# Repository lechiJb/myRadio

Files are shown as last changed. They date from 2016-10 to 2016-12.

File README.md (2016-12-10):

# myRadio – ESP8266 WLAN radio

This project is based at following templates from Espressif:

ESP8266_MP3_DECODER
https://github.com/espressif/ESP8266_MP3_DECODER.git

ESP8266_RTOS_SDK
https://github.com/espressif/ESP8266_RTOS_SDK.git

The project provides a WLAN radio, based on an ESP8266-chip.
Audio-playback is streamed by use of the I2S-interface and an external I2S-DAC-chip.
All settings (stream-URL, stream-Port, WLAN-settings) are adjustable by an integrated HTML-server.

In chapter/folder “Hardware” you can find information about used hardware for this project.

Inside the project there are also CAD-file for a housing (see chapter “CAD” below) 
and simulation-files for calculating crossover network-components (see chapter “Boxsim” below). 

##Hardware
As esp-board I used following NodeMCU-Board:
https://github.com/nodemcu/nodemcu-devkit-v1.0

It has a esp12e-board integrated, but this code runs on a esp12f-board as well (other boards will also run, 
but I only tested esp12e and esp12f-boards).
Some users tested a esp12-board without success!!!!
For MP3-decoding a chip called PCM5102 is used. There are many cheep breakout-boards available. 
To select a stream-channel, a potentiometer is used. I used a linear potentiometer but a standard one is also fine.
All other used components are optional and can be replaced or removed depending of your project!

Following there is a list of all used components:
	Controller:
- NodeMCU-board https://github.com/nodemcu/nodemcu-devkit-v1.0
- PCM5102 breakout-board http://www.ebay.com/itm/Assembled-Board-PCM5102-DAC-Decoder-I2S-Player-32bit-384K-Beyond-ES9023-PCM1794-/311402292006

All following components are optional. They are used in my radio, 
but if you like to implement this code into your system, you might need other / less components 

 Amplifier:
- DROK® TA2024B amplifier-board https://www.amazon.com/DROK-Computer-Amplifier-Electric-Capacity/dp/B00C03YYCK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

Stream-Change:
- Linear potentiometer 10K mono http://www.ebay.com/itm/ALPS-Schieberegler-RSA0N12-Schiebeweg-100mm-Potentiometer-Poti-Fader-/260967189845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

Power-supply:
- Salcar Power-Supply 12V 3A 36W https://www.amazon.de/gp/product/B00LFB4GC6/ref=oh_aui_detailpage_o03_s00?ie=UTF8&psc=1
- Mini DC-DC step down converter http://www.ebay.com/itm/10pcs-Mini-360-DC-DC-4-75V-23V-to-1V-17V-Buck-Converter-Step-Down-Power-supply-/272362239425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
- Slide-Switch 2-way (for disconnecting power-supply from NodeMCU in case of USB-connection) 
- Connector for power supply C6 inclusive power-switch http://www.conrad-electronic.co.uk/ce/en/product/718564/IEC-connector-C6-Plug-horizontal-mount-Total-number-of-pins-2-PE-25-A-Black-1-pcs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 

Bluetooth-connection:
- KRC-86B http://www.ebay.com/itm/KRC-86B-CSR8630-Bluetooth-4-0-Module-Stereo-Audio-Receiver-Amplifier-Board-ST-/172339536663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

Speaker
- Monacor SP40 https://www.monacor.com/de-de/monacorinternational/marken/monacor/beschallungstechnik/lautsprechertechnik/hi-fi-breitbandlautsprecher/sp-40/
- Dayton ND20FA
http://www.daytonaudio.com/index.php/nd20fa-6-3-4-neodymium-dome-tweeter.html

Crossover Network
- Mundorf air coil L100, 2,2 mH/0,83 Ohm
- Mundorf air coil  L71, 0,47 mH/0,57 Ohm
- Capacitor MKT 10,0 uF / 250Vdc
- Capacitor MKT 2,2 uF / 250Vdc
- Resistor MOX5 12 Ohm 2%
- Resistor MOX5 1,0 Ohm 2%

## Compile code
For a successful code-compiling following components are required:

Linux operation system (used for Project: Debian 9.0 Stretch, others should work as well).
Also a virtual-machine should be fine.

esp-open-sdk:
	https://github.com/pfalcon/esp-open-sdk.git

gtkterm (optional, is used for reviewing serial output for debugging):
	Run following code in a terminal-window:
		sudo apt-get install gtkterm 

1. Clone and compile esp-open-sdk like described in the repository.

2. Clone this repository to your local computer

3. Edit following file “<path_to_repository>/mp3/compile-script.sh” by using a standard-editor like gedit or notepad++. Following entries must be adjusted:

		#-----------General settings -------------------
		ESPTOOL_PATH=/home/christian/Dokumente/esp8266/esp-open-sdk/esptool/esptool.py
		CROSSCOMPILER_PATH=/home/christian/Dokumente/esp8266/esp-open-sdk/xtensa-lx106-elf/bin

		#-----------Project settings -------------------
		#Keep PORT empty, to not flash the chip
		PORT=/dev/ttyUSB0	

		SDK_PATH=/home/christian/Dokumente/esp8266/myRadio

		PROJECT_PATH=$SDK_PATH/mp3

		BIN_PATH=$SDK_PATH/bin

		BINARY_FILE_1=$BIN_PATH/eagle.flash.bin
		START_BYTE_1=0x00000

		BINARY_FILE_2=$BIN_PATH/eagle.irom0text.bin
		START_BYTE_2=0x20000

		UART_SPEED=115200
		START_UART_AFTERWARDS=1

	Description:

		 ESPTOOL_PATH 		Path to esptool.py-file (used for flashing program at esp-chip)

		 CROSSCOMPILER_PATH 	Path to cross-compiler (included in esp-open-sdk)

		 PORT 			Link to Serial-Port, which is used for flashing esp-chip		 

		 SDK_PATH 		Path to esp-open-sdk

		 START_UART_AFTERWARDS	Start gtkterm after successful code-compiling. If gtkterm is not available, set this parameter to 0

	All other values are project-related and should not be changed!

4. Connect esp-chip to computer
5. Start code-compiling and flashing by running scirpt “compile-script.sh” with root privilegs:
	sudo ./<path_to_repository>/mp3/compile-script.sh

##How to use
Adjust settings by using html-server:

	1. switch poti to total maximum value (end-position of poti)
	2. After some seconds the esp-chip opens a wlan-hot-spot with SSID "myRadio" and no password.
	3. Connect to this hotspot
	4. Open your browser (google-chrome and firefox tested) and go to webside "http://192.168.4.1"
		
		Following adjustments are possible:

		WLAN-SSID		SSID for your home-network
		WLAN-Password		Password to your home-network

		Channel-count		Number of stream-channels, which should be used+

		For each channel:
		Link to channel		Link to stream-channel (without "http://")
		Port to channel		Port to stream-channel (often port 80)

		Save to flash		Save all settings to flash of esp-chip

	5. To exit config-server-mode, select another channel by changing poti-position
	6. Reboot device by refreshing homepage in browser or by disconnecting and connecting power-supply again
	7. Ready!!

Selecting channel
	
	Just use poti to select different channels...

Volume control
	
	Volum has to be controlled by the amplifier, which is connected to PCM5102-device.

##CAD
I designed a housing for my radio by using a web-CAD-service called OnShape:

	Link to CAD-Software:	https://www.onshape.com/
	Link to project:	https://cad.onshape.com/documents/0631abc9282a401a9c4bd0fe/w/ab4baf43f92f08b8f3445f90/e/15931d366a16f0a984bb5bd2

In folder "CAD" you can find all CAD-files and Drawings, which I created for this project.
After building all parts by use of plywook, I used some fleece inside the speaker box to avoid oscilation of echo effects.

After assembling all parts together you will need an additional front-cover for the radio. 

##Boxsim
To get really good sound, I used two speakers in my project:
	
	- Monacor SP40 
	- Dayton ND20FA
 
I also used a crossover network to optimize sound-quality. 
For simulation of the frequency-response of both speaker, I used an application called "Boxsim":

	Link to homepage: http://www.boxsim.de/	
	Link to download: http://www.boxsim.de/download/Boxsim120en.zip

In folder called "Boxsim" you can find my Boxsim-project.
To get a perfect sound, the frequency-response should be as straight as possible. 
In my project there is still a peak avalable at 5000Hz.
The sound, which I get, sounds really great, but I can heard some small "scratches" if someone speaks.
I don't know the reason for it. Maybe the esp-output is not perfect, some materials starts to oscilate, 
or the frequency-response is not perfect.
But I am really happy with the sound, so I will not optimize it any more.

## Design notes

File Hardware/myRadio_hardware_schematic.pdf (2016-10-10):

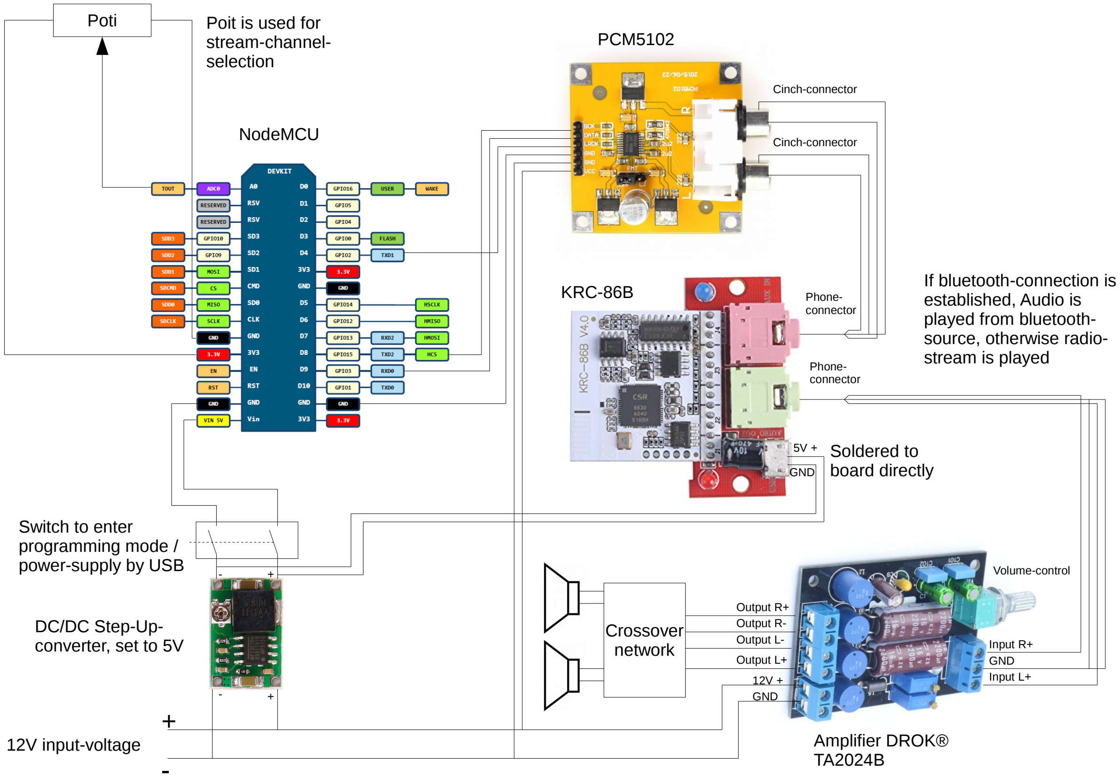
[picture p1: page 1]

Poti

NodeMCU

DC/DC Step-Upconverter, set to 5V

PCM5102

12V input-voltage

Switch to enter
programming mode /
power-supply by USB

+

Phoneconnector

Phoneconnector

Volume-control

Input R+

Input L+

GND

GND

12V +

5V +

GND

Cinch-connector

Cinch-connector

Soldered to
board directly

KRC-86B

+

+

Output R+

Output L+

Output L-

Output R- Crossover
network

Poit is used for
stream-channelselection

If bluetooth-connection is established, Audio is
played from bluetoothsource, otherwise radiostream is played

Amplifier DROK®
TA2024B

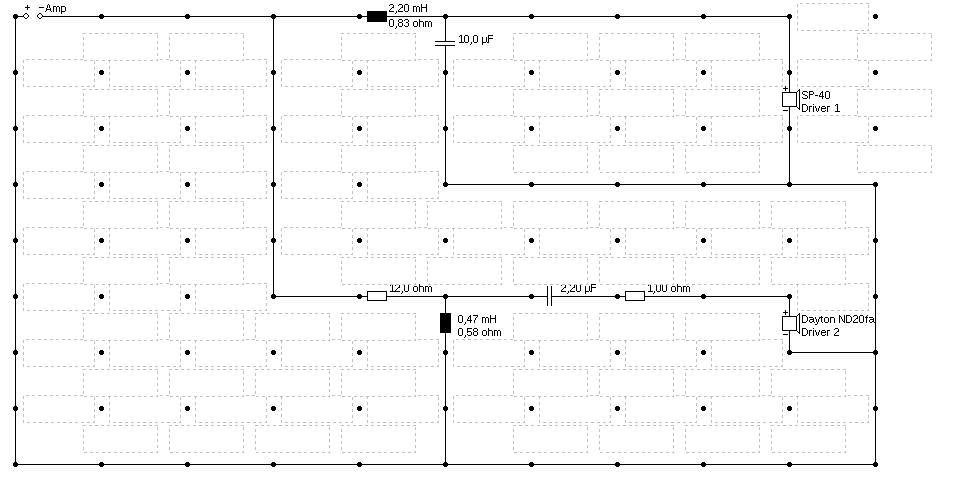
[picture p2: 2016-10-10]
Boxsim/Crossover_network.png

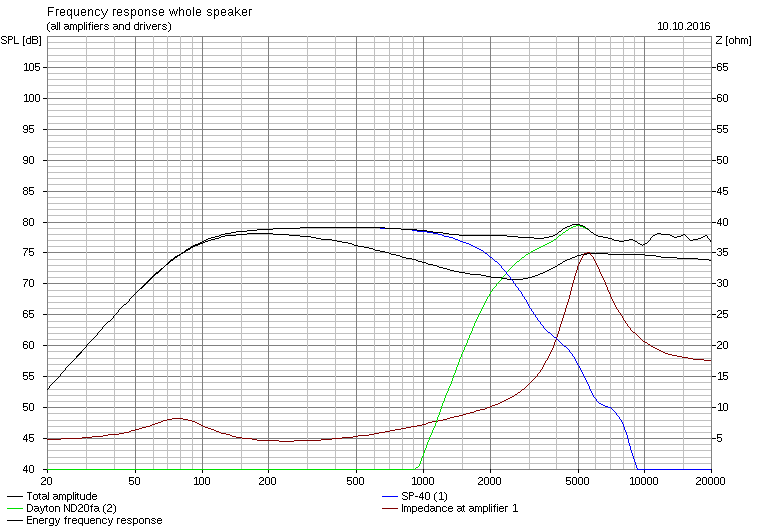
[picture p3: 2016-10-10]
Boxsim/Frequency_response.png

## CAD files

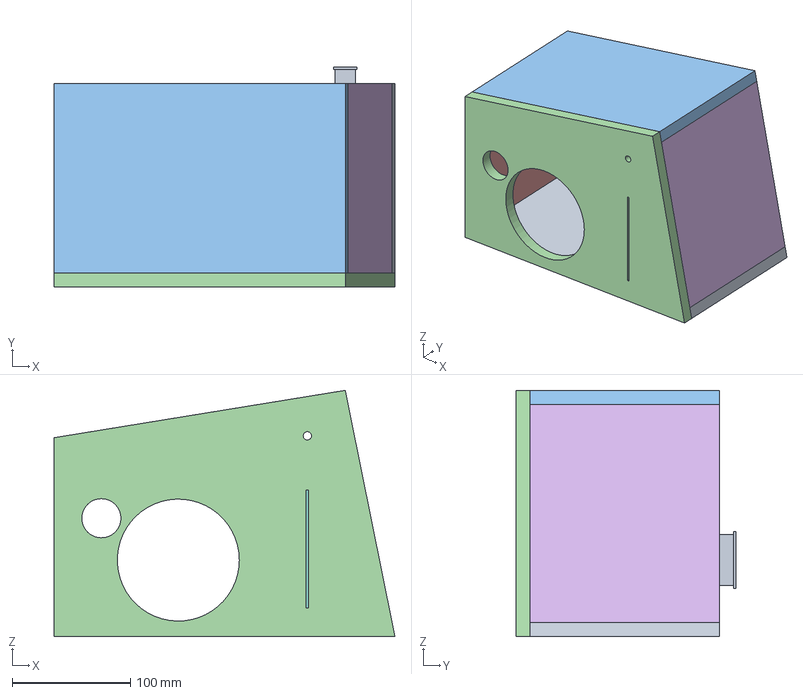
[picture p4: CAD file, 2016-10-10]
CAD/Assembly/Assembly 1.step
288.0 x 186.0 x 208.0 mm
Bodenplatte
Deckel1
Deckel2
Frontplatte
Abgrenzung
Seite_Links
Seite_Rechts
Netzteil

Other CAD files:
CAD/Drawings_DWG/myBox2 - Bodenplatte Drawing 1.dwg
CAD/Drawings_DWG/myBox2 - Abgrenzung Drawing 1.dwg
CAD/Drawings_DWG/myBox2 - Deckel2 Drawing 1.dwg
CAD/Drawings_DWG/myBox2 - Deckel1 Drawing 1.dwg
CAD/Drawings_DWG/myBox2 - Frontplatte Drawing 1.dwg
CAD/Drawings_DWG/myBox2 - Seite_Links Drawing 1.dwg
CAD/Drawings_DWG/myBox2 - RÃ¼ckplatte Drawing 1.dwg

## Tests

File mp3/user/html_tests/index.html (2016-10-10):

# myRadio - Settings

## Channel - count

How many radio-channels do you like to use?

## Channel - links

Link to channel 1:

Write data to flash

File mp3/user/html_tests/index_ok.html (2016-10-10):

# myRadio - Response

## Settings OK

Back to main-page

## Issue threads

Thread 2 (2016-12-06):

flash - Header-data does not match -1

Testi89, 2016-12-06:
When I flash the ESP with your code, I get the following error:

HW init. Wait for WIFI
mode : sta(a0:20:a6:0b:e7:05)
add if0
flash - Header-data does not match -1
flash - Err read header
init - Faild to read Flash
init - Write WLAN-Data
init - Write Channel-Data
channel - SetStream-Count, count=1
channel - StreamCount_old = 0
channel - SetStream-Host
channel - SetStream-Path, i=0, len=28
channel - SetStream-Port 0, port = 80
adc 223
adc - new stream = 0
START CLIENT MODE
scandone
wifi - SSID: Test_Pass
WIFI SSID Test_SSID set
WIFI Pass Test_Pass set
scandone
no Test_SSID found, reconnect after 1s
reconnect

Flashing was done to a new ESP12F with 32Mb flash, I also flashed esp_init_data_default.bin to 0x3fc000.

Maybe you can help? Thanks a lot!

lechiJb, 2016-12-10:
Hi!

after flashing you have to set the system to server-mode first.
You can do following steps:

1. Switch poti to maximum value ("adc 1024").
2. Board should boot in server mode ("START SERVER MODE")
3. You can search at a laptop or smartphone for a wlan hotspot called "myRadio" and connect to this hotspot.
4. Open a browser and go to homepage "http://192.168.1.4".
5. Setup your wlan-settings and channel-settings (press "OK" button after each setting to check, if entry is valid).
6. Press button "Write data to flash" to save all settings at flash of ESP.
7. now you can set the poti to a different value und no ESP should connect to your WLAN and to your defined stream-server after a reboot.

Greets,

Christian

Testi89, 2017-01-07:
Hello Christian,
now it is working, but I have a lot of drop-outs. ESP is connected 9 mbit/s.
Any ideas?
Thanks,
Pete

lechiJb, 2017-01-08:
did you changed something at following settings?

playerconfig.h
#define ADD_DEL_SAMPLES
#define ADD_DEL_BUFFPERSAMP (1000)
#define ADD_DEL_BUFFPERSAMP_NOSPIRAM (1500)

spiram_fifo.h
#define SPIRAMSIZE 1850

This lines have big influence to the audio-quality. If there are changes, audio-quality might be very low.
If you still have issues with audio-playback, you can try to install an external RAM-chip. Unfortunately I was not able to get an external RAM-chip working by use of the Node-MCU-board.

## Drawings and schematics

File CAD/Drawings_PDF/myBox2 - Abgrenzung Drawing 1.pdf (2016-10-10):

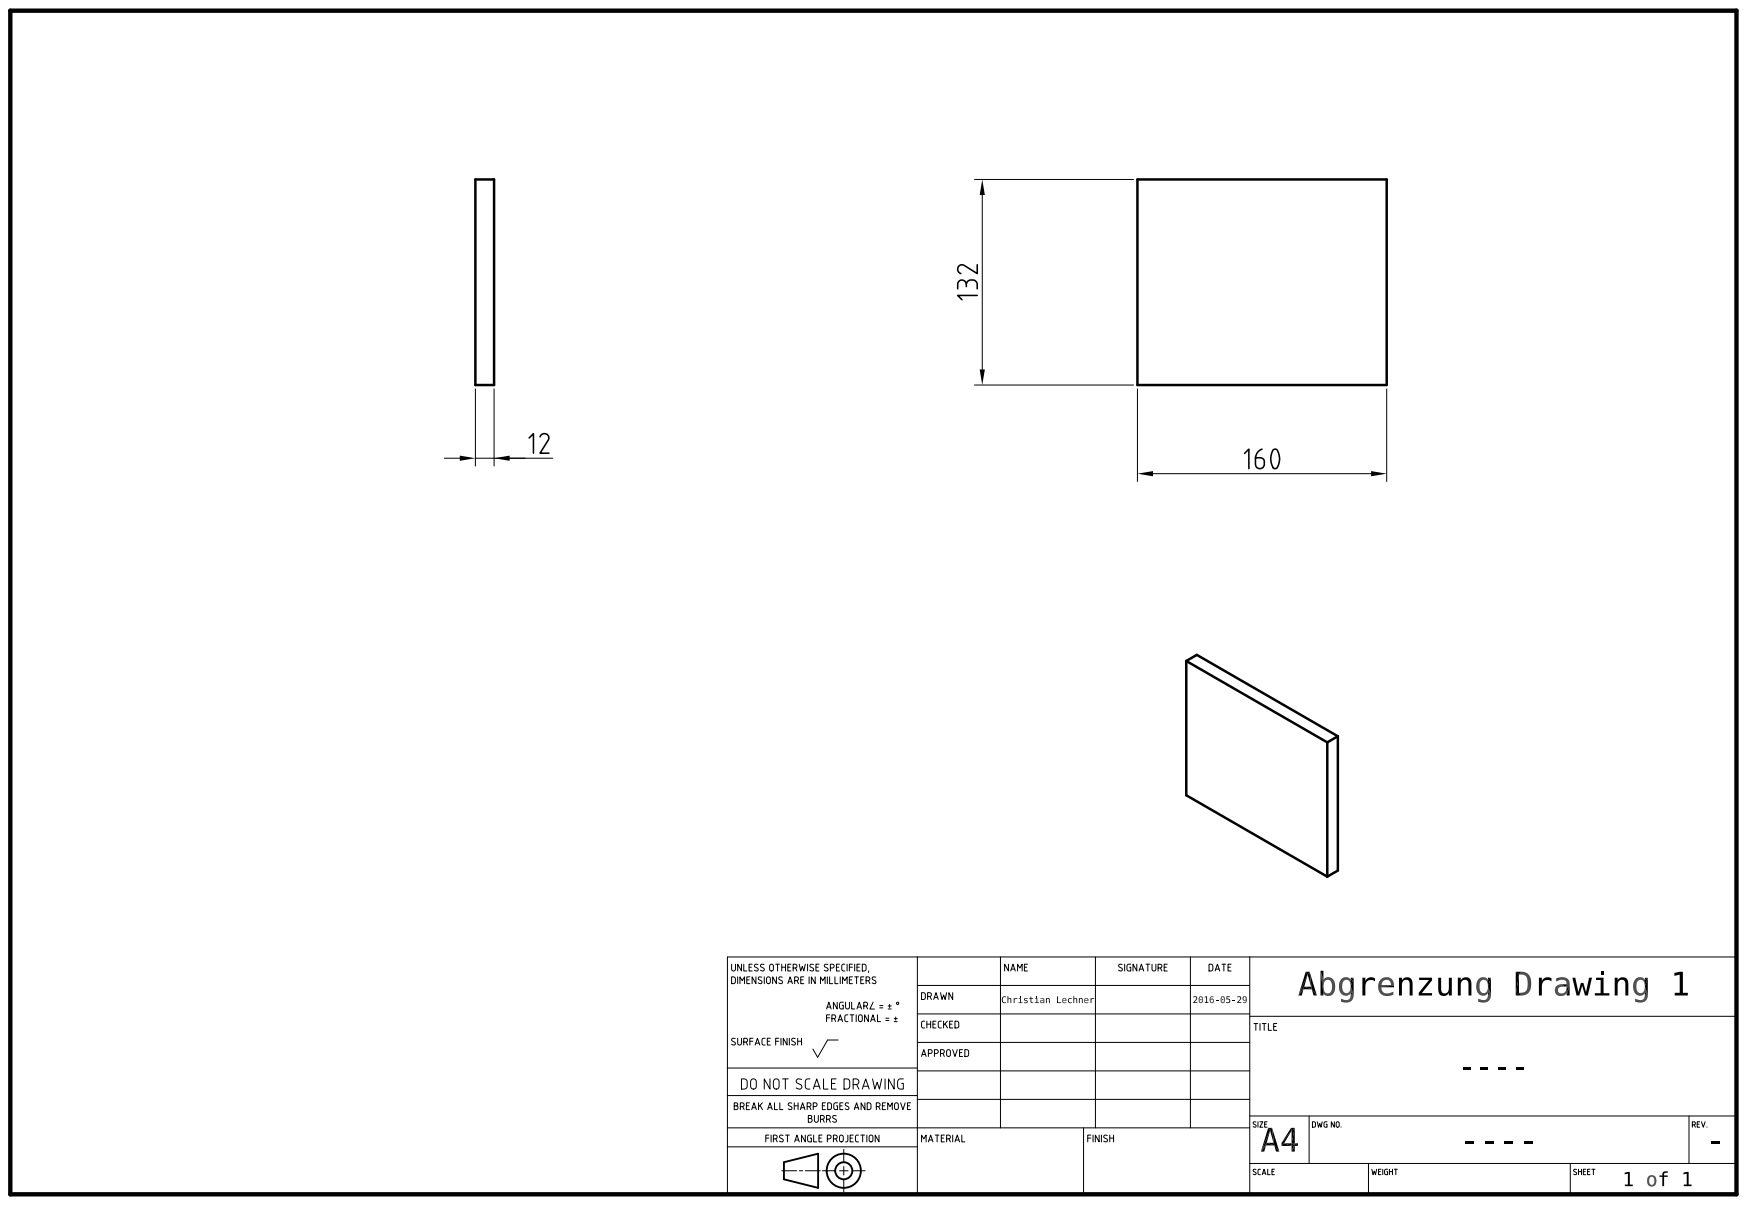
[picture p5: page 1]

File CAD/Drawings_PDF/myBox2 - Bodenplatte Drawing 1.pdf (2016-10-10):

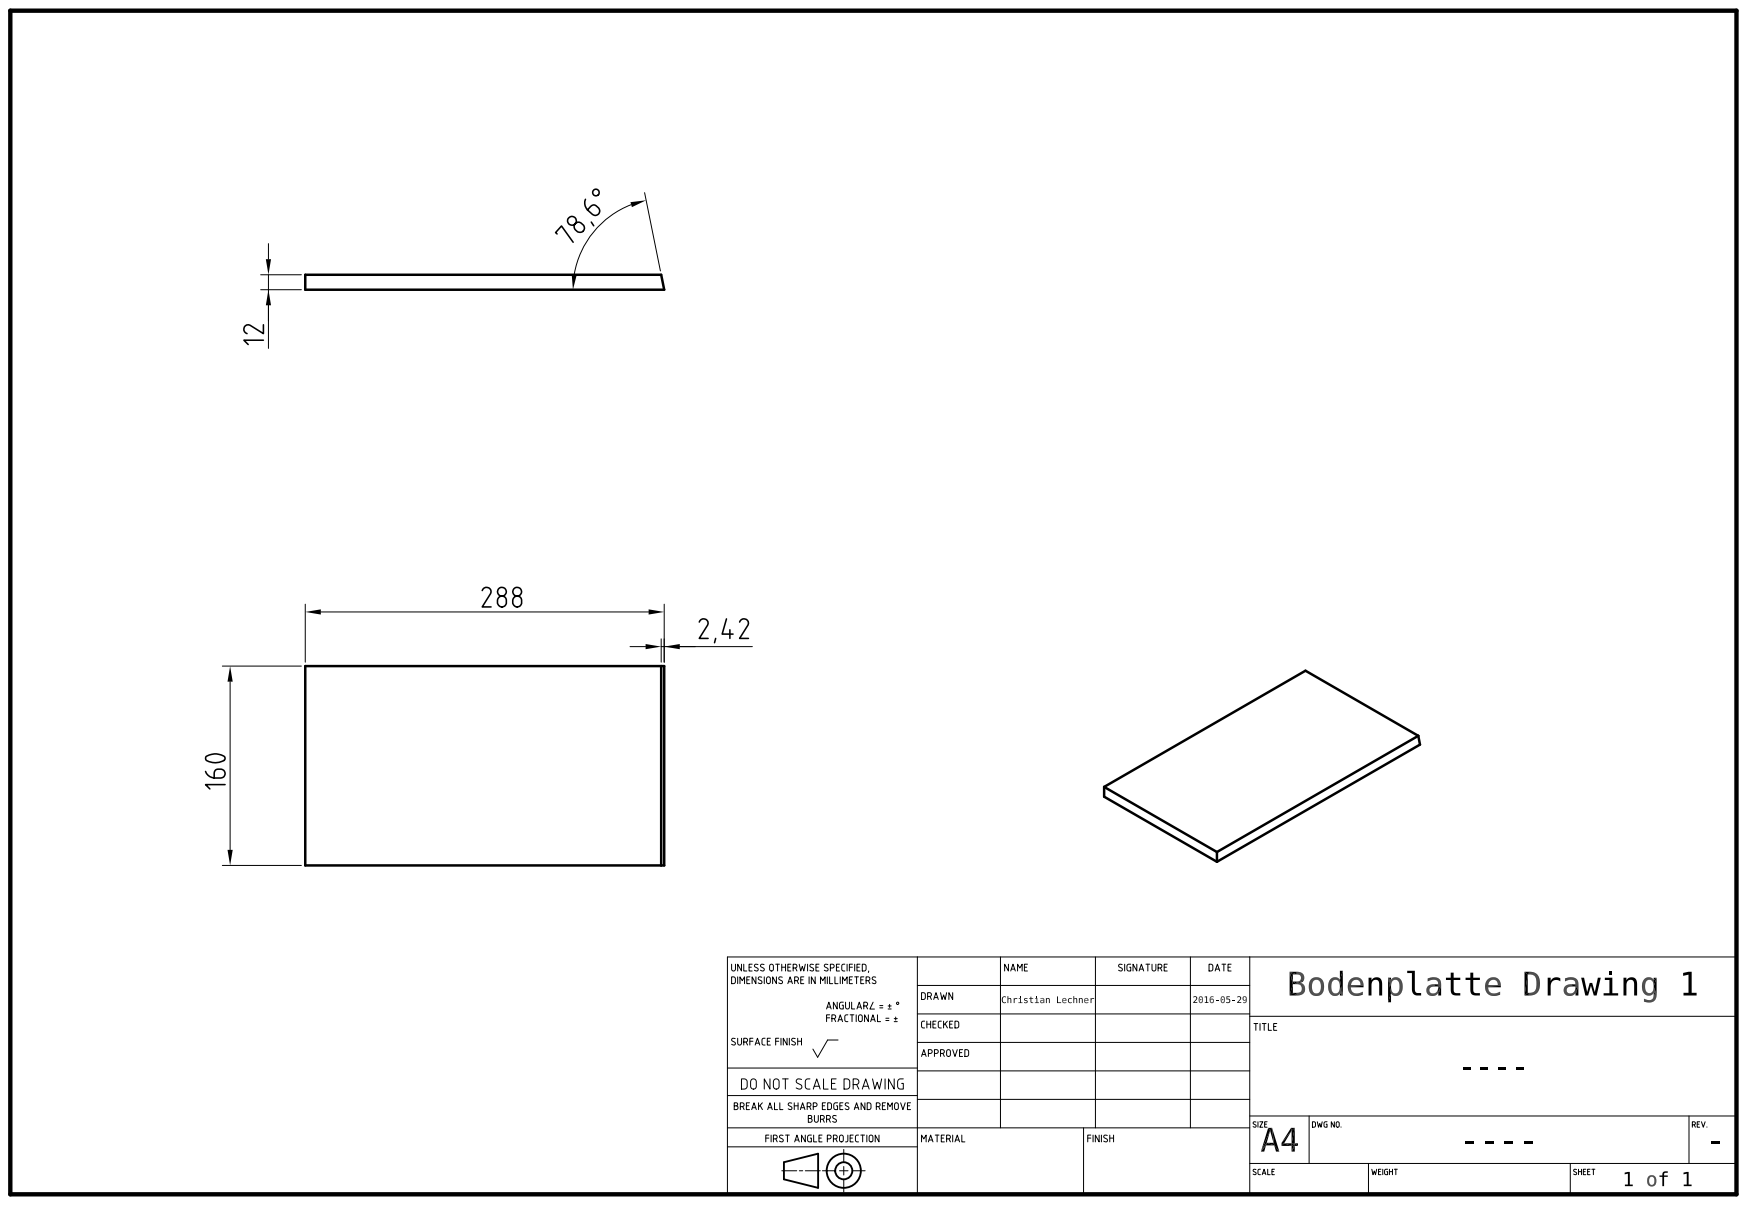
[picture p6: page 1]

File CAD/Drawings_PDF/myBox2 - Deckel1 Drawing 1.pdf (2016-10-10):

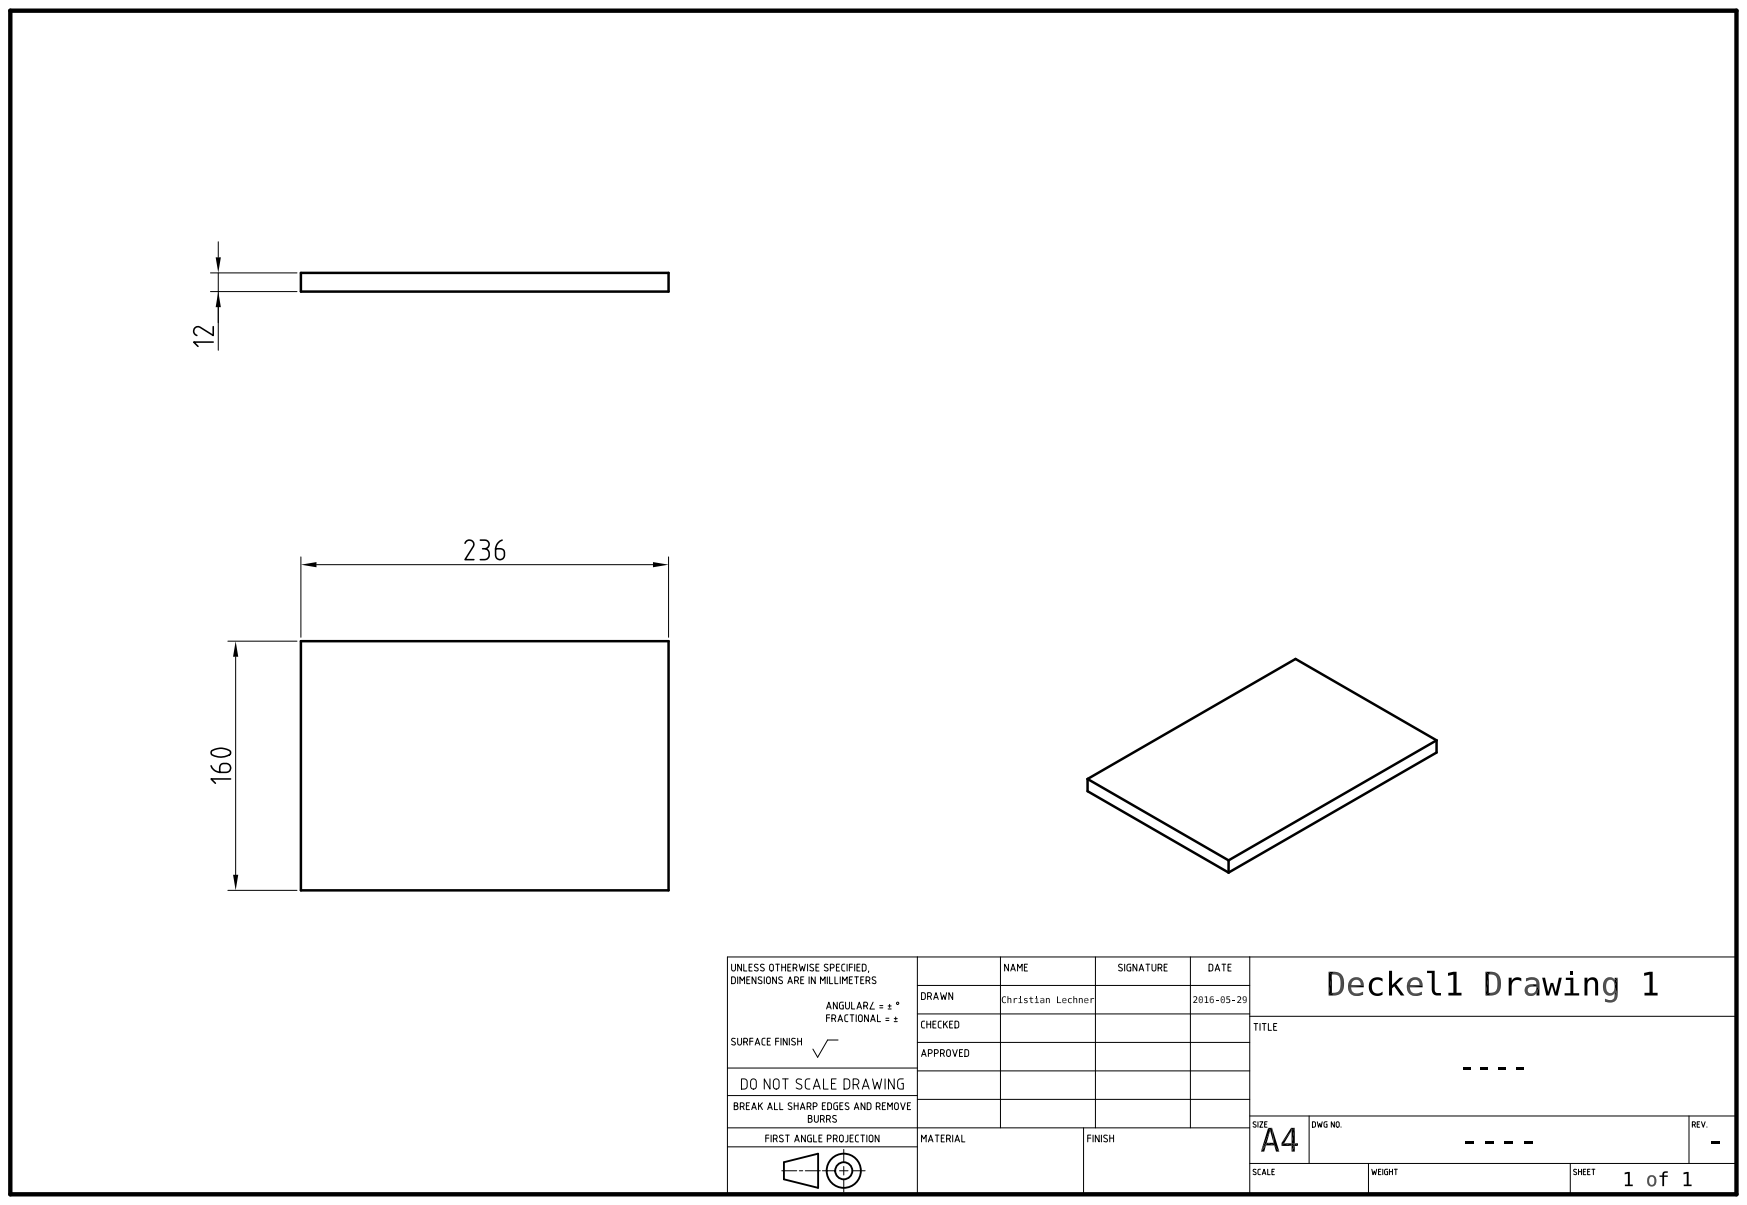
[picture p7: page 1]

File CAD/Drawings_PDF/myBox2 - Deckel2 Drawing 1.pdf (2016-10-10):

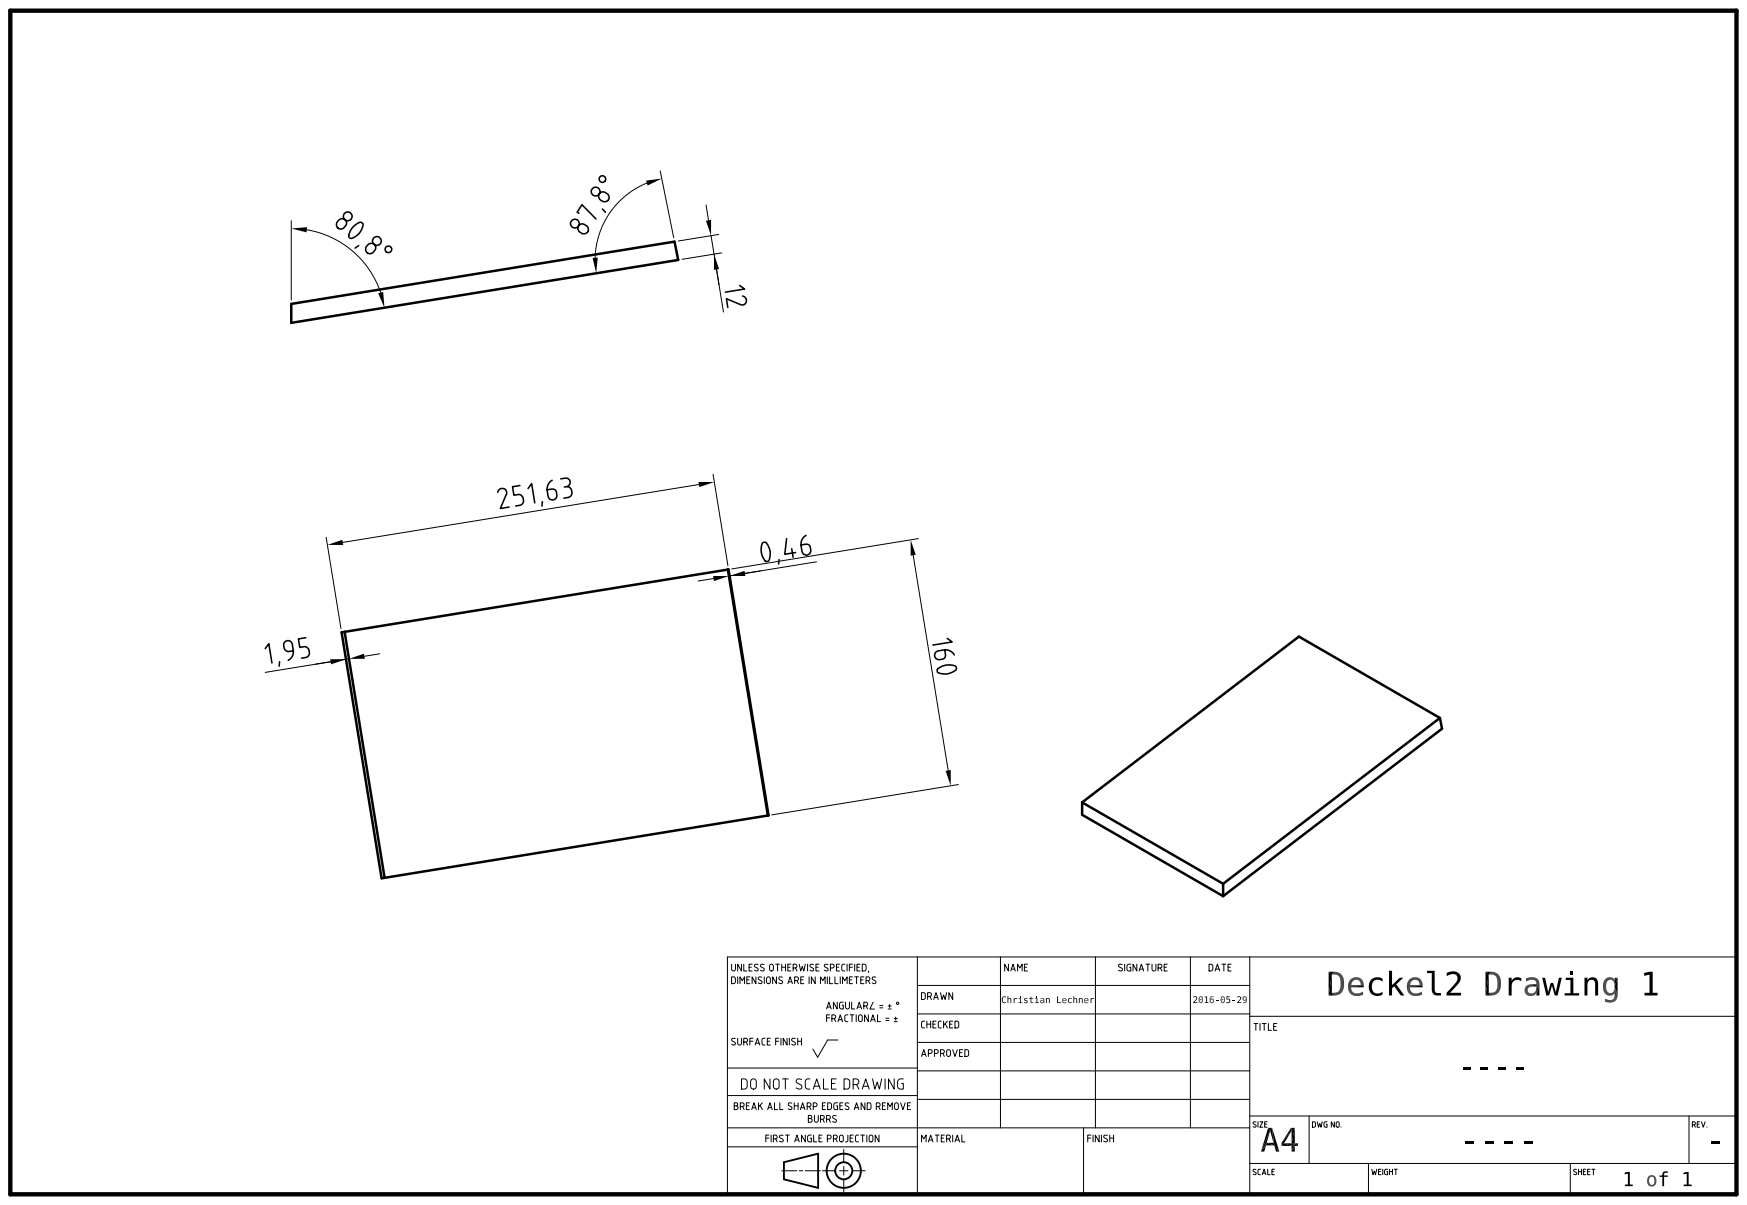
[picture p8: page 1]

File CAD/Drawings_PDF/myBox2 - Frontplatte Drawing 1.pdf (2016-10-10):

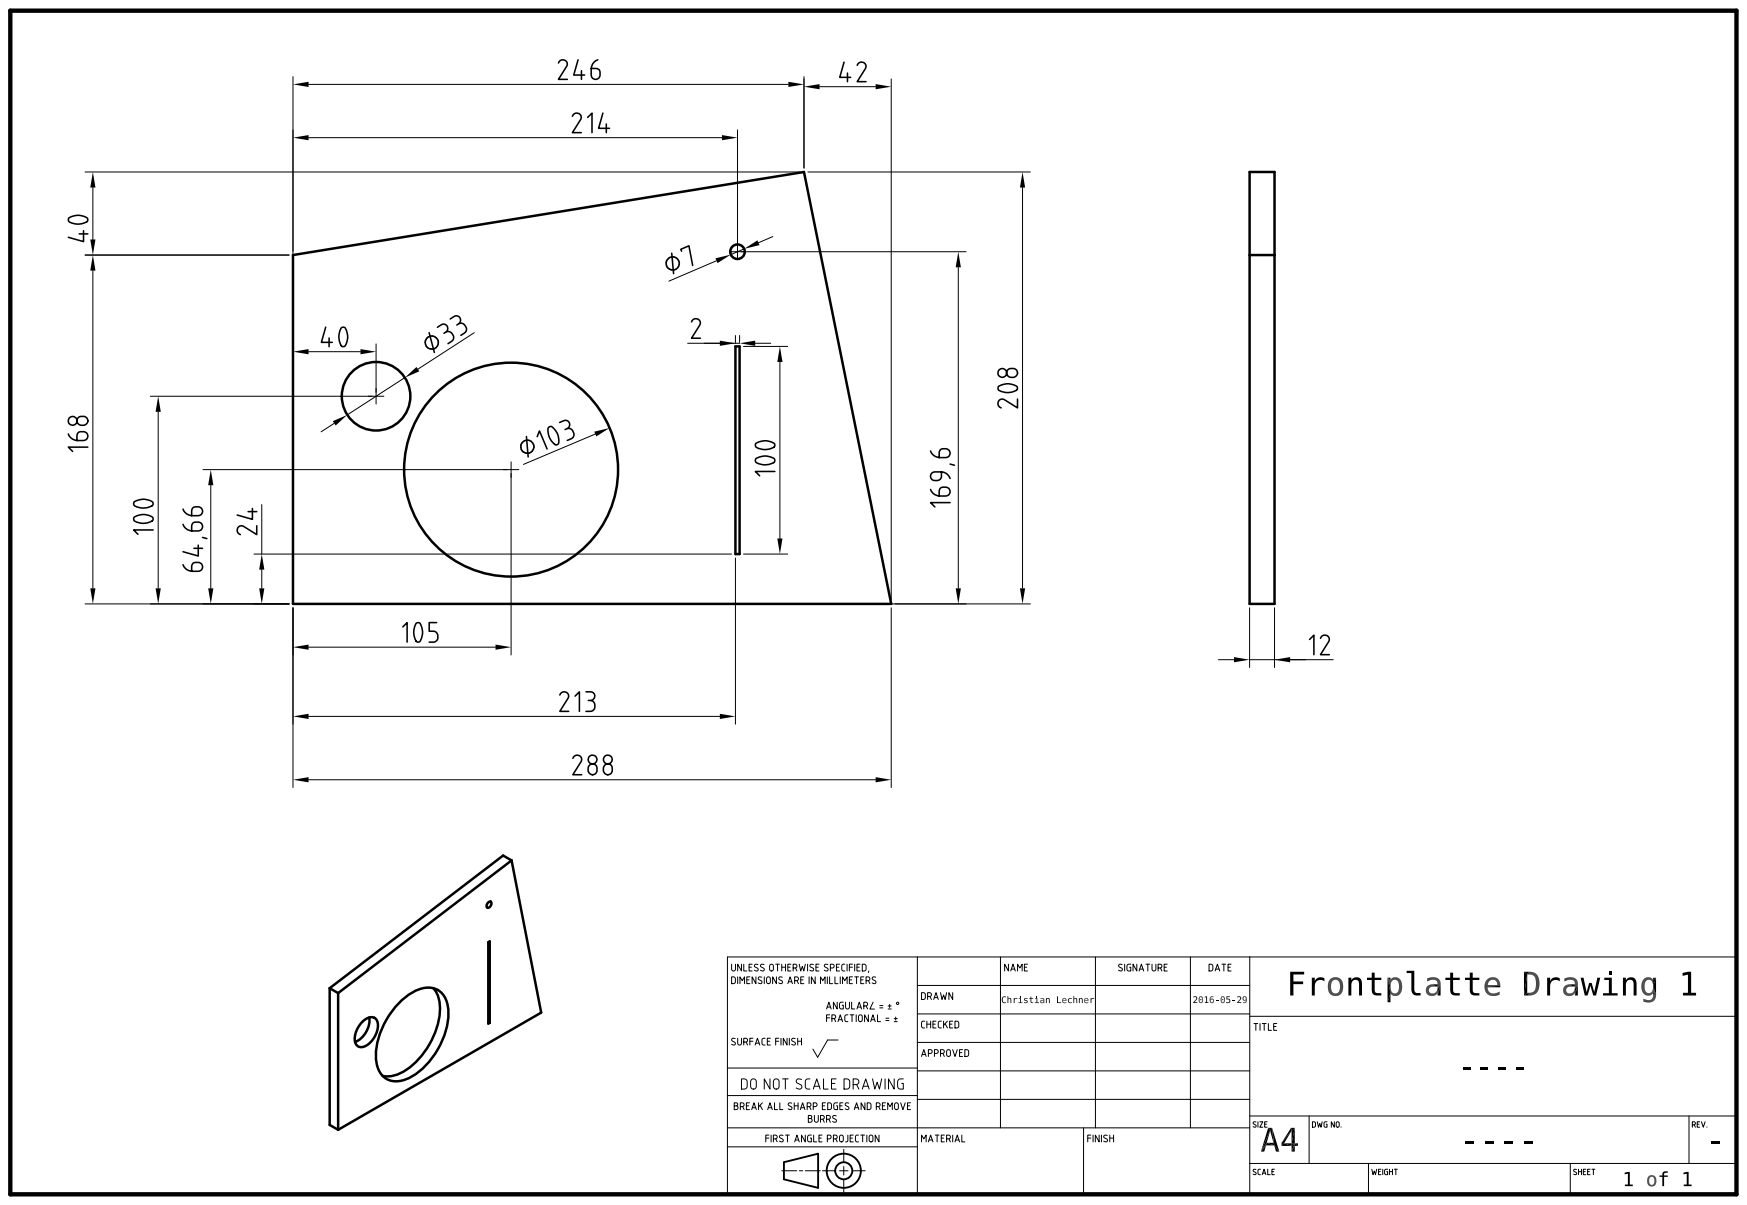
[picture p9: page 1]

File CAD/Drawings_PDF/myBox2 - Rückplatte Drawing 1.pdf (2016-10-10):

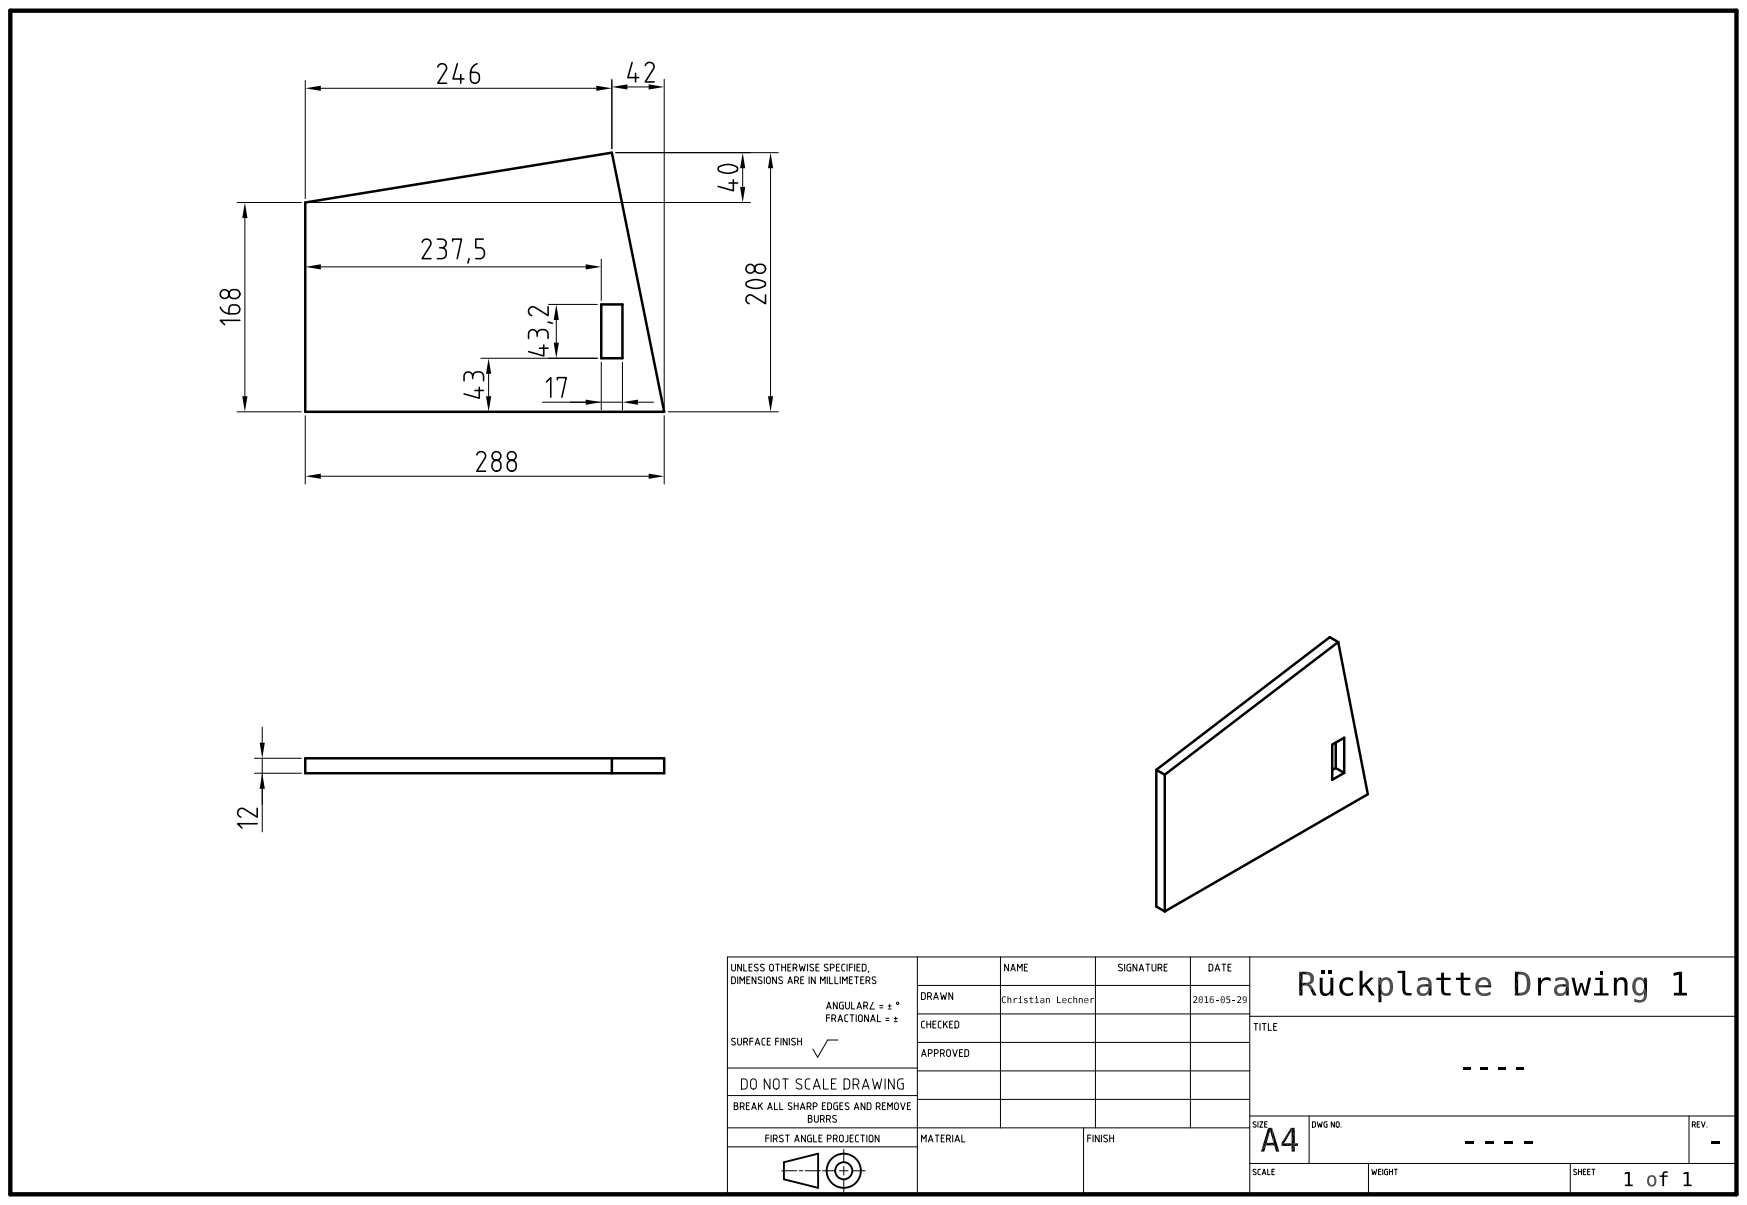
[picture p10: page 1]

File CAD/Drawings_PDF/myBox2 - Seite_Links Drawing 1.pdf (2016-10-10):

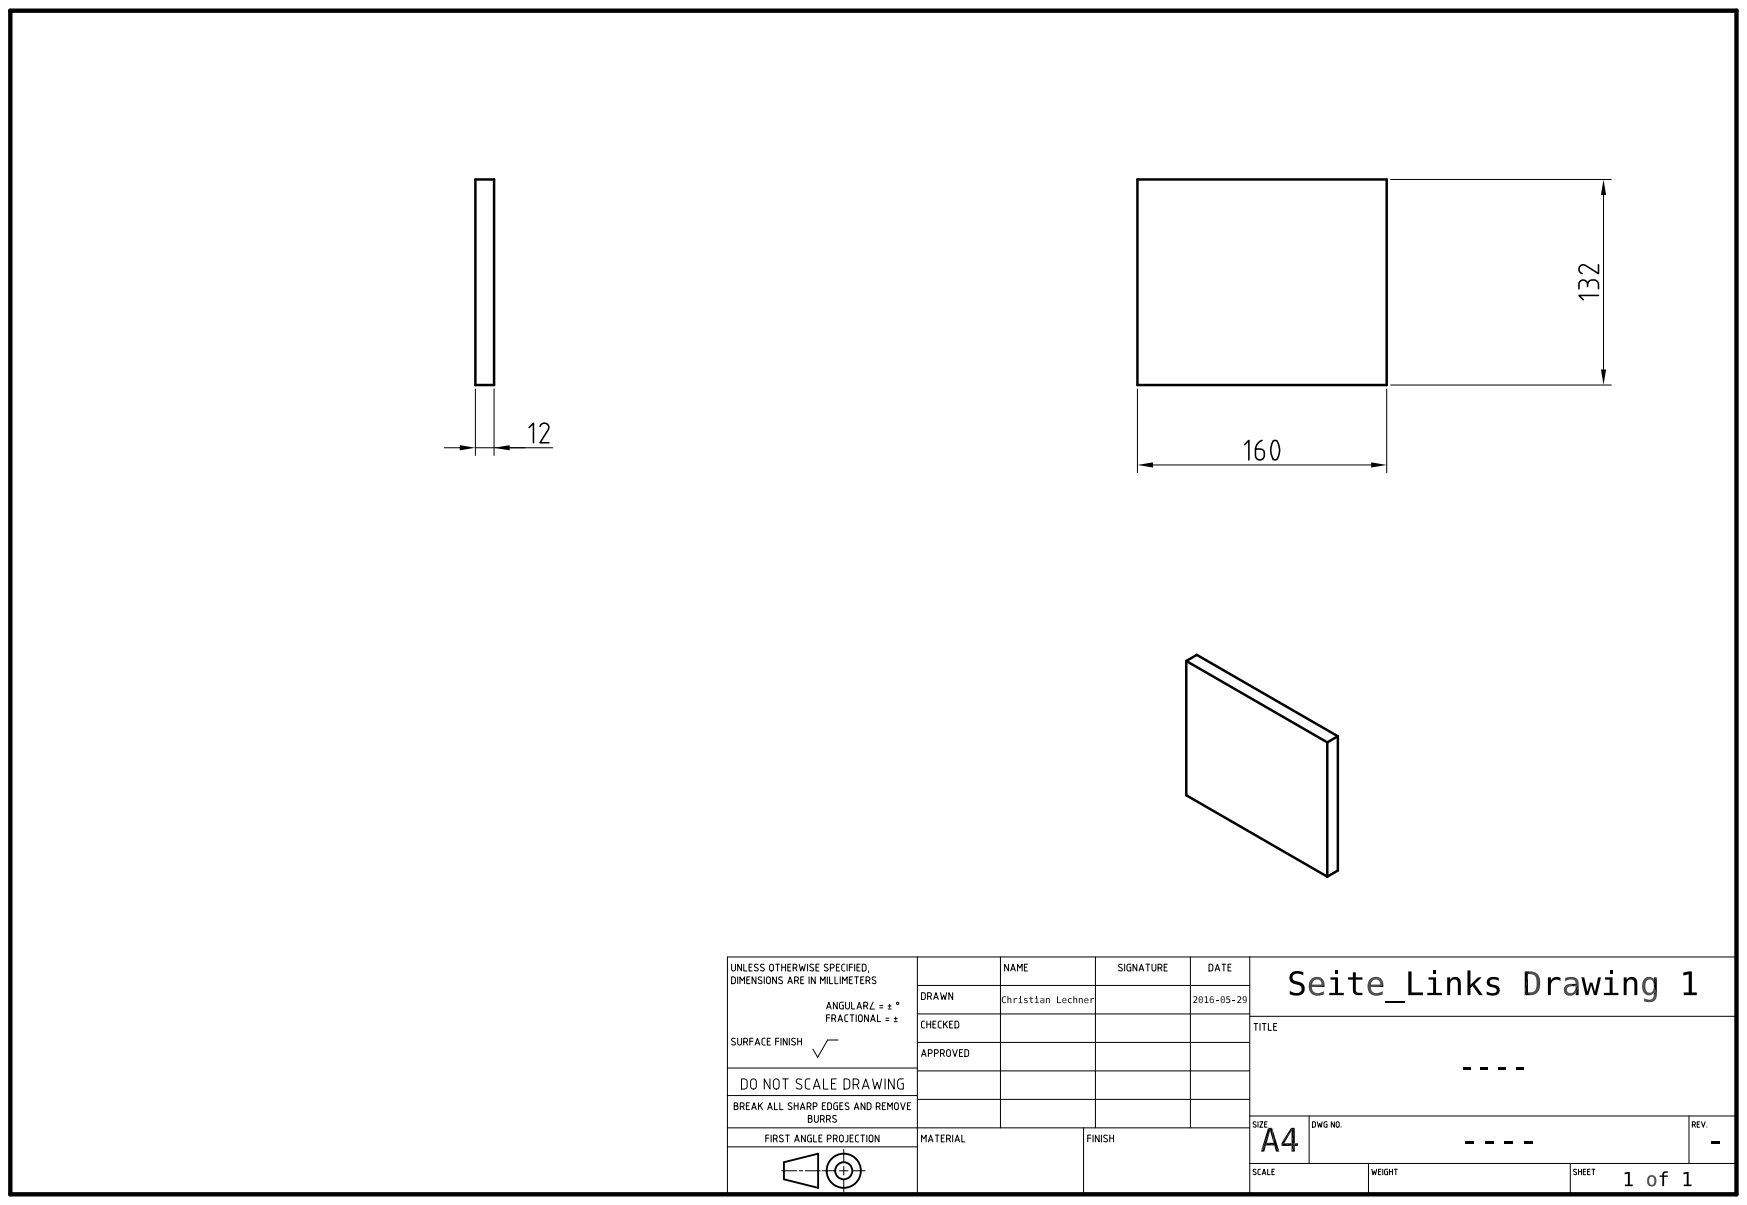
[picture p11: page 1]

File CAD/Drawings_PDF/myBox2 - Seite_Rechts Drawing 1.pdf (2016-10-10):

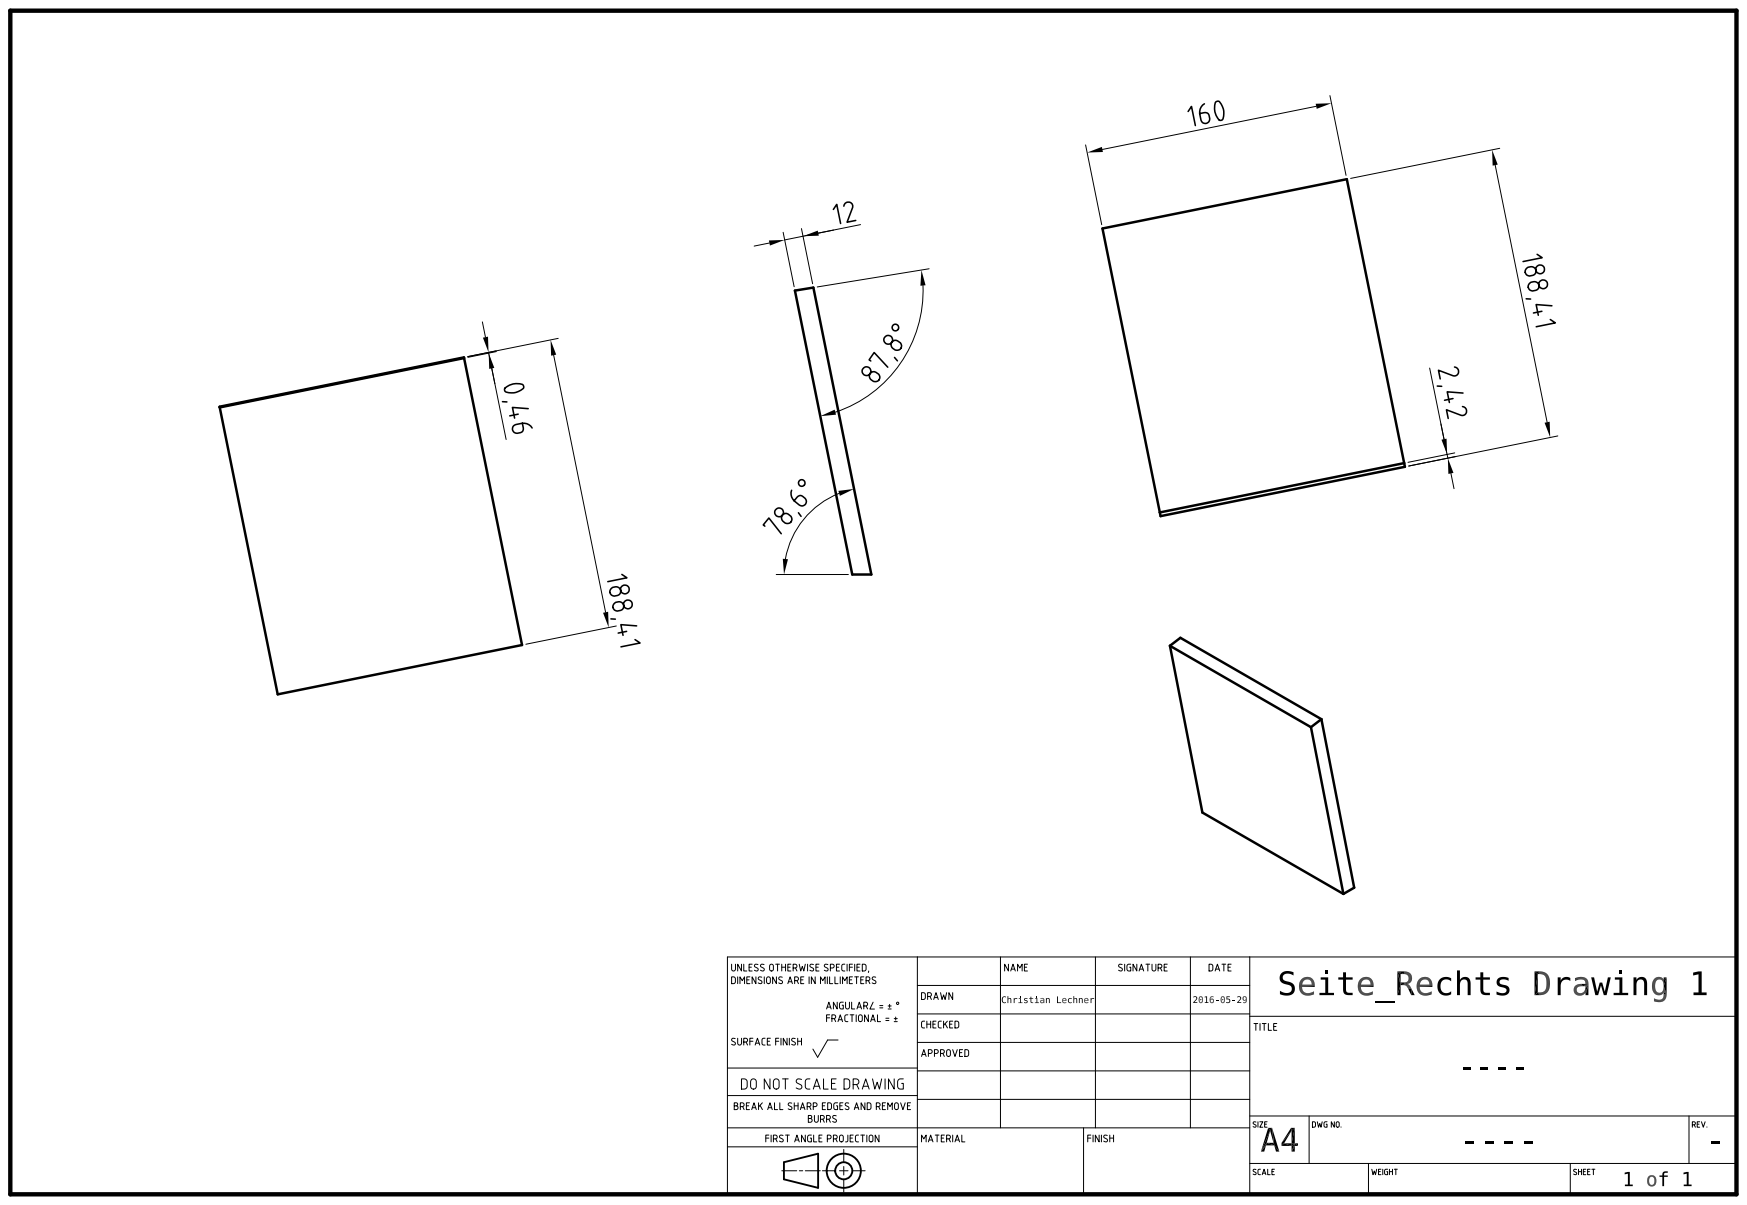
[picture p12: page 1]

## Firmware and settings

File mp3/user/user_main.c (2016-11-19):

/******************************************************************************
 * Copyright 2013-2015 Espressif Systems
 *
 * FileName: user_main.c
 *
 * Description: Main routines for MP3 decoder.
 *
 * Modification history:
 *     2015/06/01, v1.0 File created.
*******************************************************************************/
/******************************************************************************
 * Modifications applied by Christian Lechner 2016/10/06
 *
*******************************************************************************/

#include "esp_common.h"

#include "freertos/FreeRTOS.h"
#include "freertos/task.h"
#include "freertos/semphr.h"
#include "freertos/queue.h"

#include "lwip/sockets.h"
#include "lwip/dns.h"
#include "lwip/netdb.h"
#include "lwip/api.h"

#include "spiram_fifo.h"
#include "playerconfig.h"
#include "webserver.h"
#include "channel.h"
#include "mad_helper.h"




//Priorities of the reader and the decoder thread. Higher = higher prio.
#define PRIO_READER 11
#define PRIO_MAD 1


//Default values for channel and Wlan
#define DEFAULT_SSID "Test_SSID"
#define DEFAULT_PASS "Test_Pass"

#define DEFAULT_CHANNEL_HOST "mp3ad.egofm.c.nmdn.net"
#define DEFAULT_CHANNEL_PATH "/ps-egofm_192/livestream.mp3"
#define DEFAULT_CHANNEL_PORT 80


//Get IP-Address for Host-Name
int ICACHE_FLASH_ATTR getIpForHost(const char *host, struct sockaddr_in *ip) {

	err_t err;
  	ip_addr_t addr;
	err = netconn_gethostbyname(host, &addr);
  	if (err != ERR_OK) {
		printf("Connect - ERR getIP: %d  %s\n", err, host);
		return 0;
	}
	ip->sin_family=AF_INET;
	memcpy(&ip->sin_addr, &addr, sizeof(ip->sin_addr));
	return 1;
}


//Connect to channel by using netconn-connection
//netconn-connections seems to be more stable and produces less sound-lags
struct netconn * ICACHE_FLASH_ATTR openConn_netconn(int streamID){

	int ret, n;
	struct ip_addr remote_ip; 
	err_t err;
  	ip_addr_t addr;
	struct netconn *xNetConn = NULL;


	//get IP
	err = netconn_gethostbyname(channel_getStreamHost(streamID), &remote_ip);
  	if (err != ERR_OK) {
		printf("Connect - ERR getIP: %d  %s\n", err, channel_getStreamHost(streamID));
		netconn_delete ( xNetConn );
		return NULL;
	}


	//create connection
	xNetConn = netconn_new ( NETCONN_TCP ); 
	if ( xNetConn == NULL ) { 
 		printf("Connect - ERR new con\n");
		netconn_delete ( xNetConn );
		return NULL;
	 	
	}


	//connect to server
	err = netconn_connect (xNetConn, &remote_ip, (u16_t)channel_getStreamPort(streamID) ); 
	if ( err != ERR_OK)
	{
		printf("Connect - ERR connect, ret=%d\n", ret);
		netconn_close(xNetConn); 
		netconn_delete ( xNetConn );
		return NULL;

	}


	//write request
	err = netconn_write(xNetConn, "GET ", 4, NETCONN_NOCOPY);
	if ( err != ERR_OK)
	{
		printf("Connect - ERR write, ret=%d\n", ret);
		netconn_close(xNetConn); 
		netconn_delete (xNetConn);
		return NULL;

	}
	netconn_write(xNetConn, channel_getStreamPath(streamID), strlen(channel_getStreamPath(streamID)), NETCONN_NOCOPY);
	netconn_write(xNetConn, " HTTP/1.0\r\nHost: ", 17, NETCONN_NOCOPY);
	netconn_write(xNetConn, channel_getStreamHost(streamID), strlen(channel_getStreamHost(streamID)), NETCONN_NOCOPY);
	netconn_write(xNetConn, "\r\n\r\n", 4, NETCONN_NOCOPY);

	//Receive response
	struct netbuf *nbuf;
	err = netconn_recv (xNetConn, &nbuf);
	if(err != ERR_OK){
		netbuf_delete(nbuf);
		printf("Connect - Err reading\n");
		netconn_close(xNetConn); 
		netconn_delete (xNetConn);
		return NULL;
	}
	n = (int)netbuf_len(nbuf);
	if (n<=0){
		netbuf_delete(nbuf);
		printf("Connect - Err reading\n");
		netconn_close(xNetConn); 
		netconn_delete (xNetConn);
		return NULL;
	}
	char *wbuf;
	netbuf_data(nbuf, (void**)&wbuf, (u16_t*)&n);	
	netbuf_delete(nbuf);


	printf("Connect - %s%s\n", channel_getStreamHost(streamID), channel_getStreamPath(streamID));

	return xNetConn;

}




//Reader task. This will try to read data from a TCP socket into the SPI fifo buffer.
void ICACHE_FLASH_ATTR tskreader(void *pvParameters) {

	int madRunning=0;
	int n, l, inBuf;
	struct netconn * fd;
	int t = 0;
	int ret;

	
	while(1) { 

		//Read selected channel and start connection
		channel_read();
		printf("reader - Start stream %d\n", channel_getStreamCounter());	
		fd=openConn_netconn(channel_getStreamCounter()); 
		channel_setCurrentStream(channel_getStreamCounter());

		if(fd == NULL){	//Reconnect, if connection failed...
			vTaskDelay(1000/portTICK_RATE_MS);
			continue;
		}

		printf("reader - Start Reading\n");
		t = 0;
		do{
			

			//Read from Netconn
			struct netbuf *nbuf;
			err_t err;
			err = netconn_recv (fd, &nbuf);
			if(err != ERR_OK){
				netbuf_delete(nbuf);
				printf("Err reading\n");
				break;
			}
			n = (int)netbuf_len(nbuf);

			//if there are data available, copy them to SPI-buff
			if (n>0){
				
				do {	
					char *wbuf;			
					netbuf_data(nbuf, (void**)&wbuf, (u16_t*)&n);	
					spiRamFifoWrite(wbuf, n);
				} while(netbuf_next(nbuf) >= 0);
			}
			netbuf_delete(nbuf);


			//Running MAD-Task, if not running
			if ((!madRunning) && (spiRamFifoFree()<spiRamFifoLen()/2)) {
				//Buffer is filled. Start up the MAD task. 
				//Yes, the 2100 bytes of stack is a fairly large amount but MAD seems to need it.
				if (xTaskCreate(tskmad, "tskmad", 2100, NULL, PRIO_MAD, NULL)!=pdPASS) 
					printf("play - ERR create MADTask\n");
				madRunning=1;
			}
			

			//Read channel-count every 7 read-steps to avoid laggy sound
			t+=1;
			if(t >= 20){
				t = 0;
				printf("play - Buff: %d\n", spiRamFifoFill());

				//change channel
				channel_read();
				if(channel_getStreamCounter() != channel_getCurrentStream()){
					printf("play - Change to %d\n", channel_getStreamCounter());					
					
					//If channel is greater than maximum available channel, reboot for Server-Mode (config-mode)					
					if(channel_getStreamCounter() >= channel_getStreamCount())
						system_restart();		
					break;
				}
			}
			
		//Stop, if no more data available for reading...			
 		} while (n>0);
		

		//Close connection
		netconn_close(fd); 
		netconn_delete(fd);

	}

	vTaskDelete(NULL);
}



//Simple task to connect to an access point, initialize i2s and fire up the reader task.
void ICACHE_FLASH_ATTR tskconnect(void *pvParameters) {
	
	//Wait a few secs for the stack to settle down
	//vTaskDelay(3000/portTICK_RATE_MS);
	

	//Init Channels
	if(flash_readConfig() != 0){

		//if reading of flash failed (due to wrong header or other reason), set up default values
		printf("init - Faild to read Flash\n");
		printf("init - Write WLAN-Data\n");

		//Set default Wifi_Datas	
		wifi_setSSID(DEFAULT_SSID, strlen(DEFAULT_SSID));
		wifi_setPass(DEFAULT_PASS, strlen(DEFAULT_PASS));

		printf("init - Write Channel-Data\n");

		
		channel_setStreamCount(1);
		channel_setStreamHost(0, DEFAULT_CHANNEL_HOST, strlen(DEFAULT_CHANNEL_HOST));
		channel_setStreamPath(0, DEFAULT_CHANNEL_PATH, strlen(DEFAULT_CHANNEL_PATH));
		channel_setStreamPort(0, DEFAULT_CHANNEL_PORT);

	}

	//Read channel-setting
	channel_read();

	//If channel is greater than maximum available channel, start SERVER-MODE (config-mode)
	if(channel_getStreamCounter() >= channel_getStreamCount()){

		printf("START SERVER MODE\n");
		channel_setCurrentStream(channel_getStreamCounter());

		//Go to AP-mode
		wifi_station_disconnect();
		if (wifi_get_opmode() != SOFTAP_MODE) { 
			wifi_set_opmode(SOFTAP_MODE);
		}		

		//Set AP-Settings
		struct softap_config *config=malloc(sizeof(struct softap_config));
		memset(config, 0x00, sizeof(struct softap_config));
		sprintf(config->ssid, "myRadio");
		config->authmode = AUTH_OPEN;
		config->max_connection=2;
		wifi_softap_set_config(config);
		free(config);
		

		//Start Server-Task
		if (xTaskCreate(tskserver, "tskserver", 2100, NULL, PRIO_READER, NULL)!=pdPASS) printf("ERR create serverTask!\n");

	}
	else{
	
		printf("START CLIENT MODE\n");
		channel_setCurrentStream(channel_getStreamCounter());

		//Go to station mode
		wifi_station_disconnect();
		if (wifi_get_opmode() != STATION_MODE) { 
			wifi_set_opmode(STATION_MODE);
		}

		//Connect to the defined access point.
		struct station_config *config=malloc(sizeof(struct station_config));
		memset(config, 0x00, sizeof(struct station_config));
		sprintf(config->ssid, (const char*)wifi_getSSID());
		sprintf(config->password, (const char*)wifi_getPass());
		printf("WIFI SSID %s set\n", config->ssid);
		printf("WIFI Pass %s set\n", config->password);
		wifi_station_set_config(config);
		wifi_station_connect();
		free(config);

		//wait until IP is valid
		while(wifi_station_get_connect_status() != STATION_GOT_IP){
			vTaskDelay(500/portTICK_RATE_MS);	
		}

		//Fire up the reader task. The reader task will fire up the MP3 decoder as soon
		//as it has read enough MP3 data.
		if (xTaskCreate(tskreader, "tskreader", 200, NULL, PRIO_READER, NULL)!=pdPASS) printf("ERR create readerTask!\n");
		//We're done. Delete this task.
	}

	vTaskDelete(NULL);
}


//We need this to tell the OS we're running at a higher clock frequency.
extern void os_update_cpu_frequency(int mhz);

void ICACHE_FLASH_ATTR user_init(void) {
	//Tell hardware to run at 160MHz instead of 80MHz
	//This actually is not needed in normal situations... the hardware is quick enough to do
	//MP3 decoding at 80MHz. It, however, seems to help with receiving data over long and/or unstable
	//links, so you may want to turn it on. Also, the delta-sigma code seems to need a bit more speed
	//than the other solutions to keep up with the output samples, so it's also enabled there.

//Always enable full speed...
//#if defined(DELTA_SIGMA_HACK)
	SET_PERI_REG_MASK(0x3ff00014, BIT(0));
	os_update_cpu_frequency(160);
//#endif
	
	//Set the UART to 115200 baud
	UART_SetBaudrate(0, 115200);

	//Initialize the SPI RAM chip communications and see if it actually retains some bytes. If it
	//doesn't, warn user.
	if (!spiRamFifoInit()) {
		printf("\n\nSPI chip fail\n");
		while(1);
	}


	//Start conneciton -task
	printf("\n\nHW init. Wait for WIFI\n");
	xTaskCreate(tskconnect, "tskconnect", 500, NULL, 3, NULL);

}

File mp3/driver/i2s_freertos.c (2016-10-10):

/******************************************************************************
 * Copyright 2013-2015 Espressif Systems
 *
 * FileName: i2s_freertos.c
 *
 * Description: I2S output routines for a FreeRTOS system. Uses DMA and a queue
 * to abstract away the nitty-gritty details.
 *
 * Modification history:
 *     2015/06/01, v1.0 File created.
*******************************************************************************/

/*
How does this work? Basically, to get sound, you need to:
- Connect an I2S codec to the I2S pins on the ESP.
- Start up a thread that's going to do the sound output
- Call I2sInit()
- Call I2sSetRate() with the sample rate you want.
- Generate sound and call i2sPushSample() with 32-bit samples.
The 32bit samples basically are 2 16-bit signed values (the analog values for
the left and right channel) concatenated as (Rout<<16)+Lout

I2sPushSample will block when you're sending data too quickly, so you can just
generate and push data as fast as you can and I2sPushSample will regulate the
speed.
*/


#include "esp_common.h"

#include "freertos/FreeRTOS.h"
#include "freertos/task.h"
#include "freertos/semphr.h"
#include "freertos/queue.h"

#include "i2s_reg.h"
#include "slc_register.h"
#include "sdio_slv.h"
#include "i2s_freertos.h"

//We need some defines that aren't in some RTOS SDK versions. Define them here if we can't find them.
#ifndef i2c_bbpll
#define i2c_bbpll                                 0x67
#define i2c_bbpll_en_audio_clock_out            4
#define i2c_bbpll_en_audio_clock_out_msb        7
#define i2c_bbpll_en_audio_clock_out_lsb        7
#define i2c_bbpll_hostid                           4

#define i2c_writeReg_Mask(block, host_id, reg_add, Msb, Lsb, indata)  rom_i2c_writeReg_Mask(block, host_id, reg_add, Msb, Lsb, indata)
#define i2c_readReg_Mask(block, host_id, reg_add, Msb, Lsb)  rom_i2c_readReg_Mask(block, host_id, reg_add, Msb, Lsb)
#define i2c_writeReg_Mask_def(block, reg_add, indata) \
      i2c_writeReg_Mask(block, block##_hostid,  reg_add,  reg_add##_msb,  reg_add##_lsb,  indata)
#define i2c_readReg_Mask_def(block, reg_add) \
      i2c_readReg_Mask(block, block##_hostid,  reg_add,  reg_add##_msb,  reg_add##_lsb)
#endif
#ifndef ETS_SLC_INUM
#define ETS_SLC_INUM       1
#endif


//Pointer to the I2S DMA buffer data
static unsigned int *i2sBuf[I2SDMABUFCNT];
//I2S DMA buffer descriptors
static struct sdio_queue i2sBufDesc[I2SDMABUFCNT];
//Queue which contains empty DMA buffers
static xQueueHandle dmaQueue;
//DMA underrun counter
static long underrunCnt;

//This routine is called as soon as the DMA routine has something to tell us. All we
//handle here is the RX_EOF_INT status, which indicate the DMA has sent a buffer whose
//descriptor has the 'EOF' field set to 1.
LOCAL void slc_isr(void) {
	portBASE_TYPE HPTaskAwoken=0;
	struct sdio_queue *finishedDesc;
	uint32 slc_intr_status;
	int dummy;

	//Grab int status
	slc_intr_status = READ_PERI_REG(SLC_INT_STATUS);
	//clear all intr flags
	WRITE_PERI_REG(SLC_INT_CLR, 0xffffffff);//slc_intr_status);
	if (slc_intr_status & SLC_RX_EOF_INT_ST) {
		//The DMA subsystem is done with this block: Push it on the queue so it can be re-used.
		finishedDesc=(struct sdio_queue*)READ_PERI_REG(SLC_RX_EOF_DES_ADDR);
		if (xQueueIsQueueFullFromISR(dmaQueue)) {
			//All buffers are empty. This means we have an underflow on our hands.
			underrunCnt++;
			//Pop the top off the queue; it's invalid now anyway.
			xQueueReceiveFromISR(dmaQueue, &dummy, &HPTaskAwoken);
		}
		//Dump the buffer on the queue so the rest of the software can fill it.
		xQueueSendFromISR(dmaQueue, (void*)(&finishedDesc->buf_ptr), &HPTaskAwoken);
	}
	//We're done.
	portEND_SWITCHING_ISR(HPTaskAwoken);
}


//Initialize I2S subsystem for DMA circular buffer use
void ICACHE_FLASH_ATTR i2sInit() {
	int x, y;
	
	underrunCnt=0;
	
	//First, take care of the DMA buffers.
	for (y=0; y<I2SDMABUFCNT; y++) {
		//Allocate memory for this DMA sample buffer.
		i2sBuf[y]=malloc(I2SDMABUFLEN*4);
		//Clear sample buffer. We don't want noise.
		for (x=0; x<I2SDMABUFLEN; x++) {
			i2sBuf[y][x]=0;
		}
	}

	//Reset DMA
	SET_PERI_REG_MASK(SLC_CONF0, SLC_RXLINK_RST|SLC_TXLINK_RST);
	CLEAR_PERI_REG_MASK(SLC_CONF0, SLC_RXLINK_RST|SLC_TXLINK_RST);

	//Clear DMA int flags
	SET_PERI_REG_MASK(SLC_INT_CLR,  0xffffffff);
	CLEAR_PERI_REG_MASK(SLC_INT_CLR,  0xffffffff);

	//Enable and configure DMA
	CLEAR_PERI_REG_MASK(SLC_CONF0, (SLC_MODE<<SLC_MODE_S));
	SET_PERI_REG_MASK(SLC_CONF0,(1<<SLC_MODE_S));
	SET_PERI_REG_MASK(SLC_RX_DSCR_CONF,SLC_INFOR_NO_REPLACE|SLC_TOKEN_NO_REPLACE);
	CLEAR_PERI_REG_MASK(SLC_RX_DSCR_CONF, SLC_RX_FILL_EN|SLC_RX_EOF_MODE | SLC_RX_FILL_MODE);


	//Initialize DMA buffer descriptors in such a way that they will form a circular
	//buffer.
	for (x=0; x<I2SDMABUFCNT; x++) {
		i2sBufDesc[x].owner=1;
		i2sBufDesc[x].eof=1;
		i2sBufDesc[x].sub_sof=0;
		i2sBufDesc[x].datalen=I2SDMABUFLEN*4;
		i2sBufDesc[x].blocksize=I2SDMABUFLEN*4;
		i2sBufDesc[x].buf_ptr=(uint32_t)&i2sBuf[x][0];
		i2sBufDesc[x].unused=0;
		i2sBufDesc[x].next_link_ptr=(int)((x<(I2SDMABUFCNT-1))?(&i2sBufDesc[x+1]):(&i2sBufDesc[0]));
	}
	
	//Feed dma the 1st buffer desc addr
	//To send data to the I2S subsystem, counter-intuitively we use the RXLINK part, not the TXLINK as you might
	//expect. The TXLINK part still needs a valid DMA descriptor, even if it's unused: the DMA engine will throw
	//an error at us otherwise. Just feed it any random descriptor.
	CLEAR_PERI_REG_MASK(SLC_TX_LINK,SLC_TXLINK_DESCADDR_MASK);
	SET_PERI_REG_MASK(SLC_TX_LINK, ((uint32)&i2sBufDesc[1]) & SLC_TXLINK_DESCADDR_MASK); //any random desc is OK, we don't use TX but it needs something valid
	CLEAR_PERI_REG_MASK(SLC_RX_LINK,SLC_RXLINK_DESCADDR_MASK);
	SET_PERI_REG_MASK(SLC_RX_LINK, ((uint32)&i2sBufDesc[0]) & SLC_RXLINK_DESCADDR_MASK);

	//Attach the DMA interrupt
	_xt_isr_attach(ETS_SLC_INUM, (_xt_isr)slc_isr, NULL);
	//Enable DMA operation intr
	WRITE_PERI_REG(SLC_INT_ENA,  SLC_RX_EOF_INT_ENA);
	//clear any interrupt flags that are set
	WRITE_PERI_REG(SLC_INT_CLR, 0xffffffff);
	///enable DMA intr in cpu
	_xt_isr_unmask(1<<ETS_SLC_INUM);

	//We use a queue to keep track of the DMA buffers that are empty. The ISR will push buffers to the back of the queue,
	//the mp3 decode will pull them from the front and fill them. For ease, the queue will contain *pointers* to the DMA
	//buffers, not the data itself. The queue depth is one smaller than the amount of buffers we have, because there's
	//always a buffer that is being used by the DMA subsystem *right now* and we don't want to be able to write to that
	//simultaneously.
	dmaQueue=xQueueCreate(I2SDMABUFCNT-1, sizeof(int*));

	//Start transmission
	SET_PERI_REG_MASK(SLC_TX_LINK, SLC_TXLINK_START);
	SET_PERI_REG_MASK(SLC_RX_LINK, SLC_RXLINK_START);
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

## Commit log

2016-10-10 Add all files
    [Assembly 1.step, myBox2 - Abgrenzung Drawing 1.dwg, myBox2 - Bodenplatte Drawing 1.dwg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]
2016-11-19 reduce channel-overlapp, use max adc-value - overlapp as server-mode position, bugfix during setting new channel count, timeout for socket-accept -> poti can be used to exit server-mode
    [channel.c, spiram_fifo.c, user_main.c]
